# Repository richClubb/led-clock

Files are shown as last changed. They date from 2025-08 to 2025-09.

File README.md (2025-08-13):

# LED Clock

A desk or wall LED clock based on the LED rings 

* Neopixel ring 12 LED - https://www.adafruit.com/product/1643
* Neopixel ring 24 LED - https://www.adafruit.com/product/1586

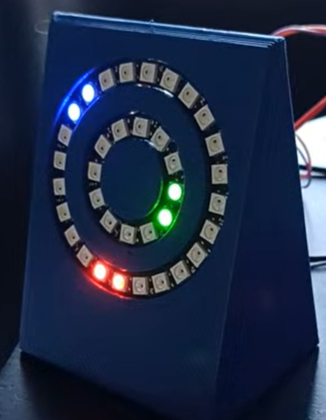
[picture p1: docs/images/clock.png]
Led Clock


## Objectives

* Easy for people to modify / use
* Use an RTC to keep time even when it's off
* Use NTP to update time
* Single code to handle all 3 clock variants
* Web page to set time
* Using serial to set config
  * Change strip that each time unit is displayed on
  * Change colour of each unit
* Self hosted network for setup
* Timer functionality
  * start, pause, reset
  * programmable / controllable from buttons on device
  * config from serial, stored in EEPROM
  * Config for: Colour, number of flashes when completed, time increment for buttons(seconds, minutes, number of minutes per press)
* Programmed in Rust
  * This is stage 2

The idea is that this is could be a product that I could sell, either as a finished clock or as a kit, but it's easy enough that it can be assembled by secondary school students.

## Demos

### Basic Functionality

[Basic time movement](./docs/images/second_minute_smooth_movement.mp4)

This video shows the movements of seconds, minutes and hours and how they blend together and move around the rings.

### Time Unit Config

[Time unit config](./docs/images/time_unit_change_colour.mp4)

This video shows the colour change config of the seconds unit. It can also be re-assigned to either of the two rings

### Timer functionality

[Timer Functionality](./docs/images/timer_function.mp4)

This video shows the timer working. The timer is for 10s and then flashes to show completion.

## Docs

* [Updates](./UPDATES.md) - Updates for the "12 Projects in 12 Months" Idea
* [Notes](./docs/NOTES.md) - General notes
* [Install](./docs/INSTALL.md) - Installing and programming

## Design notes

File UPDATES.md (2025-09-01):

# 12 Projects in 12 Months - Project 1 - LED Clock

I chose this as the first of the projects for my 12 projects in 12 months. I've had this knocking around for several years now and wanted to get it into a more finished state.

## Objectives

### Base Goals

- [x] Basic RTC functionality
- [x] Smooth motion for clock ticking
    - [x] Fix millis offset bug - Done
- [x] Ability to re-colour the units
- [x] Ability to re-allocate the led rings at runtime
- [ ] Timer
    - [x] Programmable over serial 
    - [ ] Settable with buttons
    - [x] Start 
    - [x] pause 
    - [x] reset
    - [x] Configurable colour
    - [ ] Smoother animation
- [X] EEPROM to store configuration from last serial config
    - [x] Initial prototype
    - [ ] ~~Abstraction?~~ - I don't think I'm going to bother with this
    - [X] Complete the storage
- [ ] ~~NTP functionality for setting the time~~
- [ ] ~~Web page for configuration~~
- [ ] ~~Self-hosted WiFi for configuration~~
- [x] Dont use delay!
- [ ] ~~Light adjustable intensity~~
- [ ] ~~Basic functionality in Rust~~
    - [ ] Basic RTC functionality
    - [ ] Basic LED functionality
- [x] Fix serial startup bug

### Stretch Goals

- [ ] ~~Perf test the serial interpreter~~

## Project Start

I had already done some of this before, but was basically starting from scratch. I thought I'd start by trying out several different bits of functionality based on the examples available.

I decided to try and organise the project differently, I created separate firmware sources for each experiment, this way if I can focus on the important part and ignore the rest.

### Ring Tests

These were just tests to make sure the rings work and I could address them

See [single ring test](./firmware/arduino/ring_test_single/ring_test_single.ino) and [dual ring test](./firmware/arduino/ring_test_dual/ring_test_dual.ino).

### LED ring interpolation

I started off by trying to figure out the LED movement as this would have the most significant visual difference in the finished project

What I wanted was to have a nice smooth movement of the leds walking their way around the ring, and if two units intersect then they should add their colours together on those pixels. Even if I had a 60 ring  The way I achieved this is by thinking about the time in terms of degrees

If we take the 24 ring LED as a starting point, each LED is separated by 15 degrees. In 60 seconds, each second is separated by 6 degrees, this doesn't really intersect nicely, so if you were to just light up the most appropriate LED you'd end up getting a non-regular 'tick'. The initial idea I came up with was to blend between the current LED and the next LED based on the degrees. I have 2 'modifiers' which multiply the initial colour

```
time_degree = time * degree_per_unit;

primary_led = time_degree / degree_per_pixel
secondary_led = primary_led + 1

primary_mod = (deg_per_pixel - (time_degree % deg_per_pixel)) / deg_per_pixel
secondary_mod = (time_degree % deg_per_pixel) / deg_per_pixel

led1_red, led1_green, led1_blue = red_col * primary_mod, green_col * primary_mod, blue_col * primary_mod
led2_red, led2_green, led2_blue = red_col * secondary_mod, green_col * secondary_mod, blue_col * secondary_mod
```

From this, if the LED is 'exactly' on a nice intersecting degree, then `primary_mod = 1` and `secondary_mod = 0`. As the led moves away from the intersecting degree `primary_mod` tends towards 0 and `secondary_mod` tends towards 1.

I could do something more complex with a bell curve, but this is an experiment for a later date.

One note, for the seconds. I had to calculate from millis to get a nice smooth movement, minutes interpolate on seconds, hours interpolate on minutes.

See [clock-sim](./firmware/arduino/clock_sim/clock_sim.ino) for an example.

### RTC

This was fairly simple, just using the example to read and write to the RTC.

See [serial_msg_rtc](./firmware/arduino/serial_msg_rtc/serial_msg_rtc.ino) as an example.

### Serial command interpretation

This is always a pain for Arduino projects, the serial libraries are pretty easy to use but the real pain is reading stuff off the serial buffer as it's pretty inconsistent.

I wanted to see if I can develop a general pattern for how to do this in the future.

I came up with the idea of having a `command_buffer`. Each command will have a format of `[x]=[data];` E.g. `T=2025-01-01T10:11:12;` would be the command to set the time. The serial libary reads characters into the command_buffer until the `;` is found.

Once the command is found it is then processed and validated

There are loads of different ways to interpret the data. I would like to try and put a pin in this and see if I can performance measure my approaches.

See [serial_msg_rtc](./firmware/arduino/serial_msg_interpreter/serial_msg_interpreter.ino) as an example.

#### Function pointers

I wanted to keep the code as decoupled as much as possible, so the `serial_interpreter.h` code creates function pointers that can be attached to by the main code which will already have the context and the access to the variables like the RTC or LED strips.

## Update 1 - Timers and working prototype

One use-case for this was to be as a desk clock, and a useful thing would be to have a pomodoro timer (or similar).

Functionally when the timer is active I want it to be on one of the dials exclusively, and when it is finished it should hvae some visual indication (flashing etc). Once it's finished I want everything to go back to normal.

I managed to get the main code assembled into a working example [led-clock](./firmware/arduino/led_clock/led_clock.ino). This currently has most of the working functionality.

### Issues, millisecond offset

The RTC currently only gives me second resolution, so to get the millisecond resolution I need for the smooth movement I need to use the internal arduino `millis()` function to get millisecond accuracy. At startup I create an 'offset' when the second ticks over and then subtract that from the current `millis()` value and then mod the result by 1000. This gives me a value 0 - 999 which should be the milliseconds from the current second. The problem is that over timm the clock in the arduino drifts slightly and it can get a jitter. 

There are ways to get millisecond accuracy from the DS3231 but at the moment it's on the back-burner. I think if I calculate the millis offset each second then it should be ok, it's just annoying to have to keep doing this.

### Relationships with time

I had a conversation with a friend recently after showing them the project. They are more artistic than I am and they came up with the idea that this kind of project allows people to interact with time in a way that they want. I really liked that concept, and it might also make me tempted to create a normal clock with a similar amount of customisability.

## Update 2

At this point I've got the majority of the functionality done and I'm chasing the little improvements and things are getting harder. The code has been pretty easy to modify and improve, especially the serial commands, but adding things like WiFi and NTP is going to add annoying complications that are just frustrating to have to deal with.

* If I add WiFi i need to be able to do the connection, re-connection logic. This will be frustrating with the real-time nature of the clock and I'm not sure how to handle it with a single-threaded single-core micro. I've done it with my temperature sensor and I have to pause the sampling to get it to work
* NTP could possibly spam the EEPROM significantly, so I have to be careful how much I write to it.
* The self hosted WiFi and web page is a frustration and adds a significant amount of complexity to the startup code
* The web page config itself opens questions on how to handle the showing and updating of the config, as well as displaying the page

It's easy to get to this point and just think, "fuck it, i'm happy" but I'm going to try and persevere. We try and teach our children to be resilient but as an adult I think we can also suffer from the malaise that comes with something difficult that doesn't show an immediate return

### Refactors and moving fast

I have been adding code a bit furiously and not really thinking about how maintainable it is, I think I need to actually do a line-by-line review and fix a few things. I noticed a lot of magic numbers cropping up and it's not really a good thing.

I'm a great believer in the "Make it work, make it good, make it fast". And cutting some corners while getting it working is fine, but I think if you cut too many you can end up hurting things in the long run. It's good to take a step back every few commits and see how the overall trajectory of the code is looking and how you can see things moving forward with the objectives you have in mind.

This is especially important in larger projects with multiple contributors. You do have to keep an eye on the future while also keeping things grounded in the present.

### Video blog

I've yet to do a single recording for this. I think there is an element of fear putting this out into the world at large and I'm afraid of the code being judged by someone (especially employers). It's a hard thing to get over, even though I'm pretty certain that I'll probably get 3 views and nobody will care. 

## Update 3

I've got the majority of the functionality working which I'm pretty happy about at this point I've got

* General LED display
* Serial configuration
* RTC functionality
* Timer functionality
    * missing buttons
* NVM functionality

It's the WiFi stuff that is mostly remaining. The question now is do I want to keep going or try to pivot to using Rust? That is the question. I think I'll spend this weekend ( 15 / 16 / 17 August ) working on the WiFi and then after that switch over to trying to get stuff working in Rust.

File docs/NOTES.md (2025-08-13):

# Notes

## Software

I chose to use the Arduino IDE as it's easy for other people to use and modify, I want people to be able to make this their own.

The other options for this would have been the [ESP-IDF](https://idf.espressif.com/). I've not used it yet but I've seen some pretty cool projects using it, so it would have been an option, and as the devices I'm using aren't particularly complex it would have been easy to write the drivers necessary.

If I remember correctly there are examples using their own RTOS which would make commercial programming much easier. This would be a better option if the project needed more flexibility.

There is also the [ESP32 Rust](https://github.com/esp-rs) which is something I'll hopefully have chance to play around with for this project.

## Research

### Hardware

* It might be necessary for me to build the rings. Currently I've got a 12 and 24 but it would be good to focus on the proportion of the rings and not the number of leds. These shouldn't be too bad to do in KiCad or similar, using the standard WS2812 LEDs is sensible.

* I'm probably going to have to lay out a PCB at some point. I might be able to rely on the ESP32-Wroom-C3 boards but I'm not sure, I might want to build the RTC onto the board rather than having it as a plugin but I'll have to make space for the battery.

* Currently I'm focusing on the ESP32-C3 but if I'm going to go for the whole self hosted website / API behaviour then I might need to use an S3 for the dual core. One core can handle the LEDs and the other core is dedicated to the web page. This might need to be tested. https://thepihut.com/products/esp32-s3-zero-mini-development-board is a drop in replacement.

### Rust 

* I'm going to need to write libs for embedded rust. But it could be a good exercise to write a generic lib for these.
  * LED library - this probably exists
  * RTC library - This 'might' exist

## Behaviours

### Self hosted web page

* set LEDs into flashing mode when in self-hosted config mode

### Web config

* Want to be able to set most of the config from the web page, but I don't know how best to do this. Do I use the form to construct a JSON web API query and then process that? It does mean that I can have a web API for both the getting and setting of the config which seems like a good idea.

## Original Drawings 

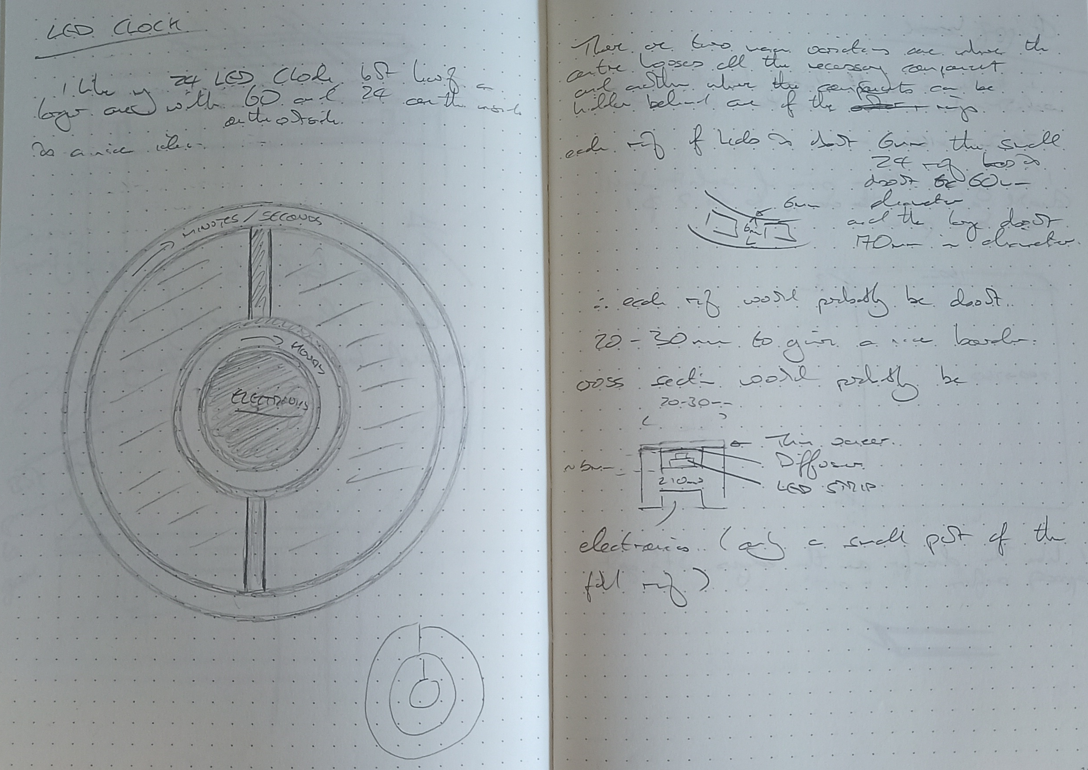
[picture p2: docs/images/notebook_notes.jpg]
original drawings


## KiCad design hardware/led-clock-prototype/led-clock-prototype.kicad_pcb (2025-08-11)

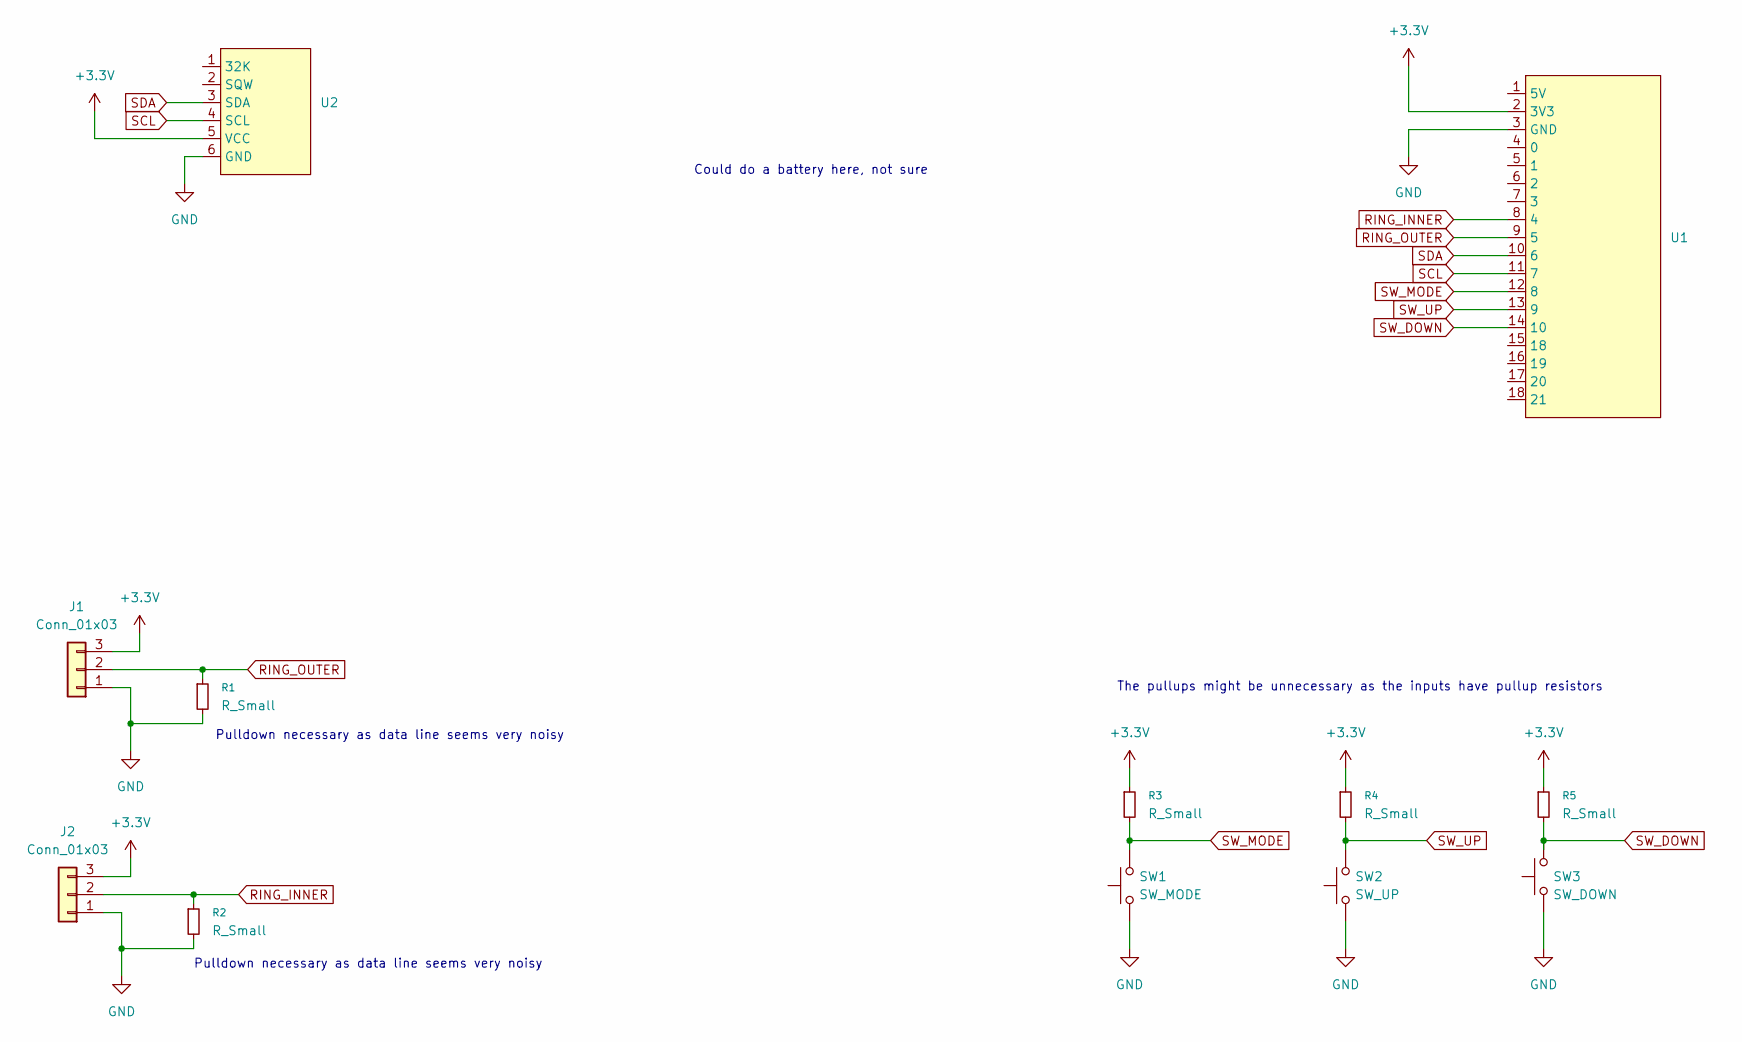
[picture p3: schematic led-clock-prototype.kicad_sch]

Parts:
J1, J2: Conn_01x03; PinHeader_1x03_P2.54mm_Vertical
R1, R2, R3, R4, R5: R_Small; R_1206_3216Metric_Pad1.30x1.75mm_HandSolder
SW1: SW_MODE; SW_PUSH_6mm
SW2: SW_UP; SW_PUSH_6mm
SW3: SW_DOWN; SW_PUSH_6mm
U1: Waveshare_ESP32_C3_Zero
U2: PinHeader_1x06_P2.54mm_Vertical

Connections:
+3.3V: J1.3, J2.3, R3.1, R4.1, R5.1, U1.2 (3V3), U2.5 (VCC)
GND: J1.1, J2.1, R1.2, R2.2, SW1.1, SW2.1, SW3.1, U1.3 (GND), U2.6 (GND)
RING_INNER: J2.2, R2.1, U1.8 (4)
RING_OUTER: J1.2, R1.1, U1.9 (5)
SCL: U1.11 (7), U2.4 (SCL)
SDA: U1.10 (6), U2.3 (SDA)
SW_DOWN: R5.2, SW3.2, U1.14 (10)
SW_MODE: R3.2, SW1.2, U1.12 (8)
SW_UP: R4.2, SW2.2, U1.13 (9)

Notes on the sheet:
Pulldown necessary as data line seems very noisy
Could do a battery here, not sure
The pullups might be unnecessary as the inputs have pullup resistors

Board: 2 copper layers, 12 parts (0 on the bottom side), 9 nets, no tracks yet.

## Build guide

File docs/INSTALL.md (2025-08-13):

# Install

* Arduino IDE 2+
* DS3231 library
* ESP32-C3-Zero (waveshare) - https://www.waveshare.com/wiki/ESP32-C3-Zero
* Adafruit NeoPixel library

These are all you need to program the device

## Hardware

* Neopixel ring 12 LED - https://www.adafruit.com/product/1643
* Neopixel ring 24 LED - https://www.adafruit.com/product/1586
* ESP32-C3-Zero - https://thepihut.com/products/esp32-c3-mini-development-board
* DS3231 breakout - https://www.bitsboxuk.com/index.php?main_page=product_info&cPath=140_166&products_id=2760

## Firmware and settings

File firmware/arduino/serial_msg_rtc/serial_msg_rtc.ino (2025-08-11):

#include "stdlib.h"
#include "string.h"
#include <DS3231.h>
#include <Wire.h>

#define SERIAL_MESSAGE_SIZE 50

#define COMMAND_SIZE_MIN 3

#define CMD_INVALID 0

unsigned int serial_msg_index = 0;
char serial_msg[SERIAL_MESSAGE_SIZE];

DS3231 myRTC;

/*
  Time command format should be:
  [Year]-[Month]-[Day]T[Hour]:[Minute]:[Second]

  Where: 
  [Year] - 4 digits numerical [ 0000 - 9999 ]
  [Month] - 2 digits numerical [ 1 - 12 ]
  [Day] - 2 digits numerical [ 1 - 31 ]
  [Hour] - 2 digits numerical [ 00 - 24 ]
  [Minute] - 2 digits numerical [ 00 - 59 ]
  [Second] - 2 digits numerical [ 00 - 59 ]
*/
#define TIME_COMMAND_MAX_SIZE 19
#define TIME_COMMAND_MIN_SIZE 19

#define TIME_COMMAND_YEAR_START_POS 0
#define TIME_COMMAND_MONTH_START_POS 5
#define TIME_COMMAND_DAY_START_POS 8
#define TIME_COMMAND_HOUR_START_POS 11
#define TIME_COMMAND_MINUTE_START_POS 14
#define TIME_COMMAND_SECOND_START_POS 17

#define TIME_COMMAND_MONTH_DASH_POS 4
#define TIME_COMMAND_DAY_DASH_POS 7
#define TIME_COMMAND_TIME_T_POS 10
#define TIME_COMMAND_HOUR_COLON_POS 13
#define TIME_COMMAND_MINUTE_COLON_POS 16

#define TIME_CMD 1U
#define TIME_CMD_DATA_OFFSET 2
bool validate_time_command(char *ptr, unsigned int size)
{
  char year_str[5];
  char month_str[3];
  char day_str[3];
  char hour_str[3];
  char minute_str[3];
  char second_str[3];
  char *endptr;

  long year, month, day, hour, minute, second;

  // 2025-01-01T10:10:10
  if (
    (size < TIME_COMMAND_MIN_SIZE) || 
    (size > TIME_COMMAND_MAX_SIZE)
  ) return false;

  // 0 1 2 3 4 5 6 7 8 9 10 11 12 13 14 15 16 17 18
  // 2 0 2 5 - 0 1 - 0 1  T  1  0  :  1  0  :  1  0
  if (ptr[TIME_COMMAND_MONTH_DASH_POS] != '-') return false;

  if (ptr[TIME_COMMAND_DAY_DASH_POS] != '-') return false;

  if (ptr[TIME_COMMAND_TIME_T_POS] != 'T') return false;

  if (ptr[TIME_COMMAND_HOUR_COLON_POS] != ':') return false;

  if (ptr[TIME_COMMAND_MINUTE_COLON_POS] != ':') return false;

  memset(year_str, '\0', 5);
  memset(month_str, '\0', 3);
  memset(day_str, '\0', 3);
  memset(hour_str, '\0', 3);
  memset(minute_str, '\0', 3);
  memset(second_str, '\0', 3);
  
  memcpy(year_str, ptr, 4);
  memcpy(month_str, ptr + 5, 2);
  memcpy(day_str, ptr + 8, 2);
  memcpy(hour_str, ptr + 11, 2);
  memcpy(minute_str, ptr + 14, 2);
  memcpy(second_str, ptr + 17, 2);

  year = strtol(year_str, &endptr, 10);
  month = strtol(month_str, &endptr, 10);
  day = strtol(day_str, &endptr, 10);
  hour = strtol(hour_str, &endptr, 10);
  minute = strtol(minute_str, &endptr, 10);
  second = strtol(second_str, &endptr, 10);

  if ( (year < 0) || (year > 9999) ) return false;
  if ( (month < 1) || (month > 12) ) return false;
  if ( (day < 1) || (day > 31) ) return false;
  if ( (hour < 00) || (hour > 59) ) return false;
  if ( (minute < 00) || (minute > 59) ) return false;
  if ( (second < 00) || (second > 59) ) return false;

  return true;
}

/*
  Hour command format should be:
  [red],[green],[blue],[ring]
*/
#define HOUR_CMD 2U
#define HOUR_CMD_DATA_OFFSET 2
bool validate_hour_command(char *ptr, unsigned int size)
{
  Serial.println("Validating hour command");

  return false;
}

/*
  Minute command format should be:
  [red],[green],[blue],[ring]
*/
#define MINUTE_CMD 2U
#define MINUTE_CMD_DATA_OFFSET 2
bool validate_minute_command(char *ptr, unsigned int size)
{
  Serial.println("Validating minute command");

  return false;
}

/*
  Second command format should be:
  [red],[green],[blue],[ring]
*/
#define SECOND_CMD 2U
#define SECOND_CMD_DATA_OFFSET 2
bool validate_second_command(char *ptr, unsigned int size)
{
  Serial.println("Validating second command");

  return false;
}

/*
  Timer command format should be:
  [hours]:[minutes]:[seconds]
*/
#define TIMER_CMD 2U
#define TIMER_CMD_DATA_OFFSET 2
bool validate_timer_command(char *ptr, unsigned int size)
{
  Serial.println("Validating timer command");

  return false;
}

/*
  Command format should be: [command_type]=[command];

  Where command type is a single ASCII char A-Z, a-z, 0-9
*/
bool validate_command(char *ptr, unsigned int size, unsigned int *command_type_out)
{
  // probably too defensive but meh
  if (size > SERIAL_MESSAGE_SIZE) return false;
  
  if (size < COMMAND_SIZE_MIN) return false;

  if (ptr[1] != '=') return false;

  char command_type = ptr[0];

  bool result = false;
  switch(command_type)
  {
    case 'T':
      Serial.println("Found Set Time command");
      result = validate_time_command(ptr + TIME_CMD_DATA_OFFSET, size - TIME_CMD_DATA_OFFSET);
      *command_type_out = TIME_CMD;
      break;
    case 'H':
      Serial.println("Found Hour command");
      result = validate_hour_command(ptr + HOUR_CMD_DATA_OFFSET, size - HOUR_CMD_DATA_OFFSET);
      *command_type_out = HOUR_CMD;
      break;
    case 'M':
      Serial.println("Found Minute command");
      result = validate_minute_command(ptr + MINUTE_CMD_DATA_OFFSET, size - MINUTE_CMD_DATA_OFFSET);
      *command_type_out = MINUTE_CMD;
      break;
    case 'S':
      Serial.println("Found Second command");
      result = validate_second_command(ptr + SECOND_CMD_DATA_OFFSET, size - SECOND_CMD_DATA_OFFSET);
      *command_type_out = SECOND_CMD;
      break;
    case 'I':
      Serial.println("Found Timer command");
      result = validate_timer_command(ptr + TIMER_CMD_DATA_OFFSET, size - TIMER_CMD_DATA_OFFSET);
      *command_type_out = TIMER_CMD;
      break;
    default:
      return false;
  }

  if (result == false)
  {
    *command_type_out = CMD_INVALID;
    return false;
  }  

  return result;
}

void set_time(
  char *ptr,
  byte *century,
  byte *year, 
  byte *month,
  byte *day,
  byte *hour,
  byte *minute,
  byte *second)
{
  char year_str[5];
  char month_str[3];
  char day_str[3];
  char hour_str[3];
  char minute_str[3];
  char second_str[3];
  char *endptr;

  long year_int, month_int, day_int, hour_int, minute_int, second_int;

  memset(year_str, '\0', 5);
  memset(month_str, '\0', 3);
  memset(day_str, '\0', 3);
  memset(hour_str, '\0', 3);
  memset(minute_str, '\0', 3);
  memset(second_str, '\0', 3);
  
  memcpy(year_str, ptr, 4);
  memcpy(month_str, ptr + 5, 2);
  memcpy(day_str, ptr + 8, 2);
  memcpy(hour_str, ptr + 11, 2);
  memcpy(minute_str, ptr + 14, 2);
  memcpy(second_str, ptr + 17, 2);

  year_int = strtol(year_str, &endptr, 10);
  month_int = strtol(month_str, &endptr, 10);
  day_int = strtol(day_str, &endptr, 10);
  hour_int = strtol(hour_str, &endptr, 10);
  minute_int = strtol(minute_str, &endptr, 10);
  second_int = strtol(second_str, &endptr, 10);

  *century = (byte)(year_int / 100);
  *year = (byte)(year_int % 100);
  *month = (byte)month_int;
  *day = (byte)day_int;
  *hour = (byte)hour_int;
  *minute = (byte)minute_int;
  *second = (byte)second_int;

  myRTC.setClockMode(false);  // set to 24h
  //setClockMode(true); // set to 12h
  
  myRTC.setYear(*year);
  myRTC.setMonth(*month);
  myRTC.setDate(*day);
  myRTC.setHour(*hour);
  myRTC.setMinute(*minute);
  myRTC.setSecond(*second);
}

void setup() {

  // Start the I2C interface
	Wire.begin(7, 6);

  Serial.begin(115200);

  memset(serial_msg, '\0', SERIAL_MESSAGE_SIZE);
}

bool century_flag;
bool h12_flag; 
bool h24_flag;

void loop() {
  unsigned int command_type;

  // put your main code here, to run repeatedly:
  while (Serial.available() > 0)
  {
    // buffer overflow check
    if (serial_msg_index + 1 > SERIAL_MESSAGE_SIZE)
    {
      Serial.println("current command overflowed buffer, flushing buffer\n");
      serial_msg_index = 0;
      memset(serial_msg, '\0', SERIAL_MESSAGE_SIZE);
      /* should I try and intelligently flag that the current command is dirty? */
    }

    char current_char = Serial.read();
    if (current_char == '\n') continue;

    if (current_char == ';')
    {
      if (!validate_command(serial_msg, serial_msg_index, &command_type))
      {
        Serial.println("Command invalid");
        memset(serial_msg, '\0', SERIAL_MESSAGE_SIZE);
        serial_msg_index = 0;
      }

      switch(command_type)
      {
        case CMD_INVALID:
          break;
        case TIME_CMD:
          Serial.println("Setting time");
          byte century, year, month, day, hour, minute, second;
          // command should have been validated at this point
          set_time(serial_msg + TIME_CMD_DATA_OFFSET, &century, &year, &month, &day, &hour, &minute, &second);
          Serial.print("DEBUG main: Century: ");
          Serial.print(century);
          Serial.print(", year: ");
          Serial.print(year);
          Serial.print(", month: ");
          Serial.print(month);
          Serial.print(", day: ");
          Serial.print(day);
          Serial.print(", hour: ");
          Serial.print(hour);
          Serial.print(", minute: ");
          Serial.print(minute);
          Serial.print(", second: ");
          Serial.print(second);
          Serial.print("\n");
          break;
        case HOUR_CMD: // hour
          break;
        case 3: // minute
          break;
        case 4: // second
          break;
        default:
          Serial.println("Command type not supported");
          break;
      }

      serial_msg_index = 0;
      memset(serial_msg, '\0', SERIAL_MESSAGE_SIZE);
      continue;
    }

    serial_msg[serial_msg_index++] = current_char;
  }

  century_flag = false;

  byte century, year, month, day, hour, minute, second;
  year = myRTC.getYear();
  month = myRTC.getMonth(century_flag);
  day = myRTC.getDate();
  hour = myRTC.getHour(h12_flag, h24_flag);
  minute = myRTC.getMinute();
  second = myRTC.getSecond();

  Serial.print("Time: ");
  Serial.print(year);
  Serial.print("-");
  Serial.print(month);
  Serial.print("-");
  Serial.print(day);
  Serial.print("T");
  Serial.print(hour);
  Serial.print(":");
  Serial.print(minute);
  Serial.print(":");
  Serial.print(second);
  Serial.print("\n");
  delay(100);

}

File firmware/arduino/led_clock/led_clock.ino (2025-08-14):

#include "led_strip.h"
#include "time_unit.h"
#include "serial_interpreter.h"
#include "timer.h"
#include <DS3231.h>
#include <Wire.h>
#include "Preferences.h"

#define LED_DISPLAY_DELAY 100

#define OUTER_RING_NUM 60
#define OUTER_RING_PIN 3
#define OUTER_RING_INDEX 1
#define MIDDLE_RING_NUM 24
#define MIDDLE_RING_PIN 4
#define MIDDLE_RING_INDEX 2
#define INNER_RING_NUM 12
#define INNER_RING_PIN 5
#define INNER_RING_INDEX 3

LedStrip outer_ring(OUTER_RING_PIN, OUTER_RING_NUM);
LedStrip middle_ring(MIDDLE_RING_PIN, MIDDLE_RING_NUM);
LedStrip inner_ring(INNER_RING_PIN, INNER_RING_NUM);

LedStrip *led_strips[3] = {&outer_ring, &middle_ring, &inner_ring};

DS3231 rtc;
bool century = false;
bool h12Flag;
bool pmFlag;

TimeUnit hour_unit(&inner_ring, &inner_ring, &rtc, Hour, 0, 50, 0);
TimeUnit minute_unit(&middle_ring, &inner_ring, &rtc, Minute, 50, 0, 0);
TimeUnit second_unit(&middle_ring, &inner_ring, &rtc, Second, 0, 0, 50);

ClockTimer clock_timer(&middle_ring, 50, 0, 0);

#define RW_MODE false
#define RO_MODE true

Preferences stcPrefs;

/* ---------------------------------------------------------------------------- */
/* --  CONFIG FUNCTIONS ------------------------------------------------------- */
/* ---------------------------------------------------------------------------- */

void set_time(
  byte year, 
  byte month, 
  byte day, 
  byte hour, 
  byte minute, 
  byte second
)
{
  rtc.setYear(year);
  rtc.setMonth(month);
  rtc.setDate(day);
  rtc.setHour(hour);
  rtc.setMinute(minute);
  rtc.setSecond(second);
}
void (*setTimePtr)(byte, byte, byte, byte, byte, byte) = &set_time;

void set_time_unit(
  byte time_unit,
  byte ring,
  byte red,
  byte green,
  byte blue
)
{
  TimeUnit *time_unit_ptr;

  stcPrefs.begin("STCPrefs", RW_MODE);
  switch(time_unit)
  {
    case 1:
      // Hour
      time_unit_ptr = &hour_unit;
      stcPrefs.putBool("hourSet", true);
      stcPrefs.putUChar("hourRed", red);
      stcPrefs.putUChar("hourGreen", green);
      stcPrefs.putUChar("hourBlue", blue);
      stcPrefs.putUChar("hourRing", ring-1); // this is skanky
      break;
    case 2:
      // Minute
      time_unit_ptr = &minute_unit;
      stcPrefs.putBool("minuteSet", true);
      stcPrefs.putUChar("minuteRed", red);
      stcPrefs.putUChar("minuteGreen", green);
      stcPrefs.putUChar("minuteBlue", blue);
      stcPrefs.putUChar("minuteRing", ring-1);
      break;
    case 3:
      // Second
      time_unit_ptr = &second_unit;
      stcPrefs.putBool("secondSet", true);
      stcPrefs.putUChar("secondRed", red);
      stcPrefs.putUChar("secondGreen", green);
      stcPrefs.putUChar("secondBlue", blue);
      stcPrefs.putUChar("secondRing", ring-1);
      break;
  }
  stcPrefs.end();
  
  switch(ring)
  {
    case OUTER_RING_INDEX:
      time_unit_ptr->set_led_strip(&outer_ring);
      break;
    case MIDDLE_RING_INDEX:
      time_unit_ptr->set_led_strip(&middle_ring);
      break;
    case INNER_RING_INDEX:
      time_unit_ptr->set_led_strip(&inner_ring);
      break;
    default:
      Serial.println("Unknown ring");
      break;
  }
  
  time_unit_ptr->set_colours(red, green, blue);
}
void (*setTimeUnitPtr)(byte, byte, byte, byte, byte) = &set_time_unit;

void set_timer(unsigned int seconds)
{
  clock_timer.set_timer(seconds);
  
  hour_unit.switch_alt_led_strip();
  minute_unit.switch_alt_led_strip();
  second_unit.switch_alt_led_strip();

  clock_timer.start_timer();
}
void (*setTimerPtr)(unsigned int) = &set_timer;

void set_timer_config(byte ring, byte red, byte green, byte blue)
{
  clock_timer.set_colours(red, green, blue);

  stcPrefs.begin("STCPrefs", RW_MODE);
  stcPrefs.putBool("timerSet", true);
  stcPrefs.putUChar("timerRed", red);
  stcPrefs.putUChar("timerGreen", green);
  stcPrefs.putUChar("timerBlue", blue);
  stcPrefs.putUChar("timerRing", ring-1);
  stcPrefs.end();
  
  switch(ring)
  {
    case 1:
      clock_timer.set_led_strip(&outer_ring);
      break;
    case 2:
      clock_timer.set_led_strip(&middle_ring);
      break;
    case 3:
      clock_timer.set_led_strip(&inner_ring);
      break;
    default:
      Serial.println("Unknown ring");
      break;
  }
}
void (*setTimerConfigPtr)(byte, byte, byte, byte) = &set_timer_config;

void set_timer_control(unsigned int mode)
{
  switch(mode)
  {
    case 1:
      clock_timer.pause_timer();
      break;
    case 2:
      clock_timer.reset_timer();
      break;
    case 3:
      clock_timer.resume_timer();
      break;
    default:
      break;
  }
}
void(*setTimerControlPtr)(unsigned int) = &set_timer_control;


/* ---------------------------------------------------------------------------- */
/* --  MAIN FUNCTIONS --------------------------------------------------------- */
/* ---------------------------------------------------------------------------- */

void setup()
{
  Serial.begin(115200);

  Wire.begin(7, 6);

  stcPrefs.begin("STCPrefs", RO_MODE);
  bool tpInit = stcPrefs.isKey("nvsInit");

  if (tpInit == true)
  {
    if (stcPrefs.isKey("hourSet"))
    {
      hour_unit.set_colours(stcPrefs.getUChar("hourRed"), stcPrefs.getUChar("hourGreen"), stcPrefs.getUChar("hourBlue"));
      hour_unit.set_led_strip(led_strips[stcPrefs.getUChar("hourRing")]);
    }

    if (stcPrefs.isKey("minuteSet"))
    {
      minute_unit.set_colours(stcPrefs.getUChar("minuteRed"), stcPrefs.getUChar("minuteGreen"), stcPrefs.getUChar("minuteBlue"));
      minute_unit.set_led_strip(led_strips[stcPrefs.getUChar("minuteRing")]);
    }

    if (stcPrefs.isKey("secondSet"))
    {
      second_unit.set_colours(stcPrefs.getUChar("secondRed"), stcPrefs.getUChar("secondGreen"), stcPrefs.getUChar("secondBlue"));
      second_unit.set_led_strip(led_strips[stcPrefs.getUChar("secondRing")]);
    }

    if (stcPrefs.isKey("timerSet"))
    {
      clock_timer.set_colours(stcPrefs.getUChar("timerRed"), stcPrefs.getUChar("timerGreen"), stcPrefs.getUChar("timerBlue"));
    }

    stcPrefs.end();
  }
  else
  {
    stcPrefs.end();
    stcPrefs.begin("STCPrefs", RW_MODE);
    stcPrefs.putBool("nvsInit", true);
    stcPrefs.end();
  }
}

unsigned int led_index = 0;

unsigned long led_display_last = 0;
void loop()
{
  unsigned long loop_millis = millis();
  // Serial interpreter check
  if (Serial.available())
  {
    process_serial_data();
  }

  // LED Display loop
  if ( (loop_millis - led_display_last) > LED_DISPLAY_DELAY )
  {
    outer_ring.clear();
    middle_ring.clear();
    inner_ring.clear();

    if(clock_timer.is_finished())
    {
      hour_unit.restore_led_strip();
      minute_unit.restore_led_strip();
      second_unit.restore_led_strip();
    }

    hour_unit.update();
    minute_unit.update();
    second_unit.update();
    clock_timer.update();

    outer_ring.clear();
    middle_ring.update();
    inner_ring.update();
    led_display_last = loop_millis;
  }
}

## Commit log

2025-08-11 Moved into own repo from misc-projects
    [led-clock-prototype.kicad_pcb, led-clock-prototype.kicad_sch]
2025-08-13 Minor refactor of the led strip class
2025-08-13 corrected issue with millis offset (untested)
    [time_unit.h]
